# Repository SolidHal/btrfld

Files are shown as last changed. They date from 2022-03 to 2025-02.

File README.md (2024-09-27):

# btrfld and btrfld_ulp

Pronounced "butter-fold"

A foldable, portable sibling of the btrfly keyboard https://github.com/SolidHal/btrfly-keyboard

and a variant, the btrfld ulp (ultra low profile)

More images available in "FinishedPictures" folder
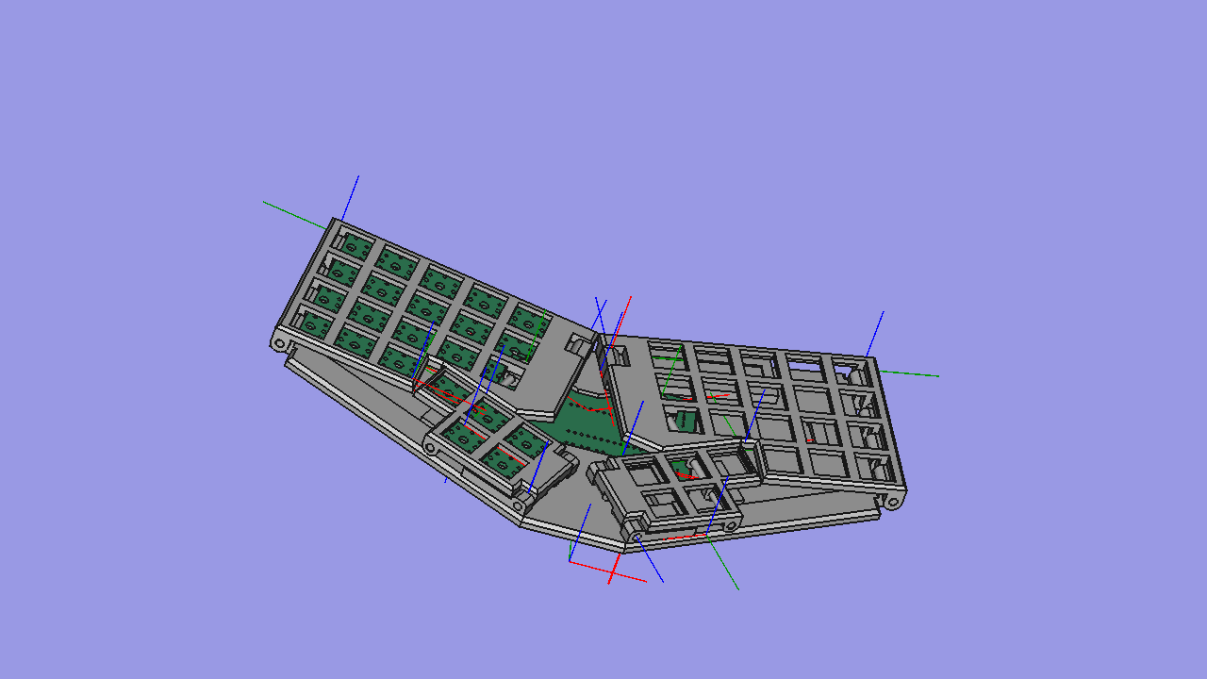
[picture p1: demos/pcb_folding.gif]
render_gif

the btrfld folding and unfolding

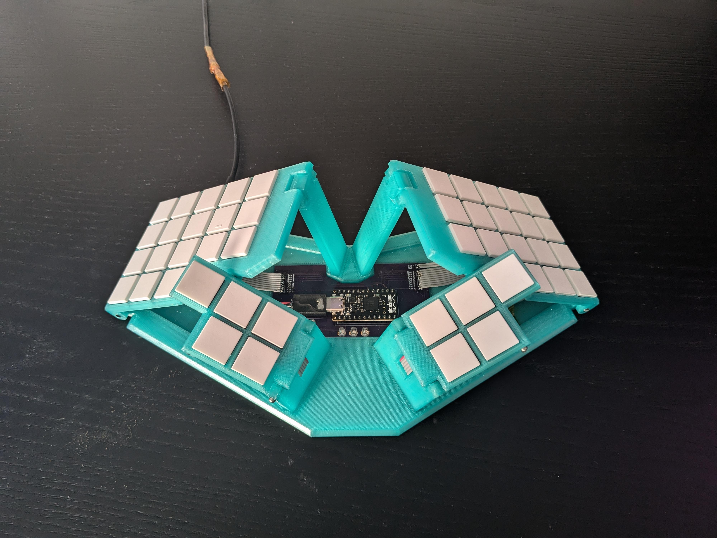
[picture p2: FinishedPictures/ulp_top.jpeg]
ulp_above

the btrfld ultra low profile (ulp) from above

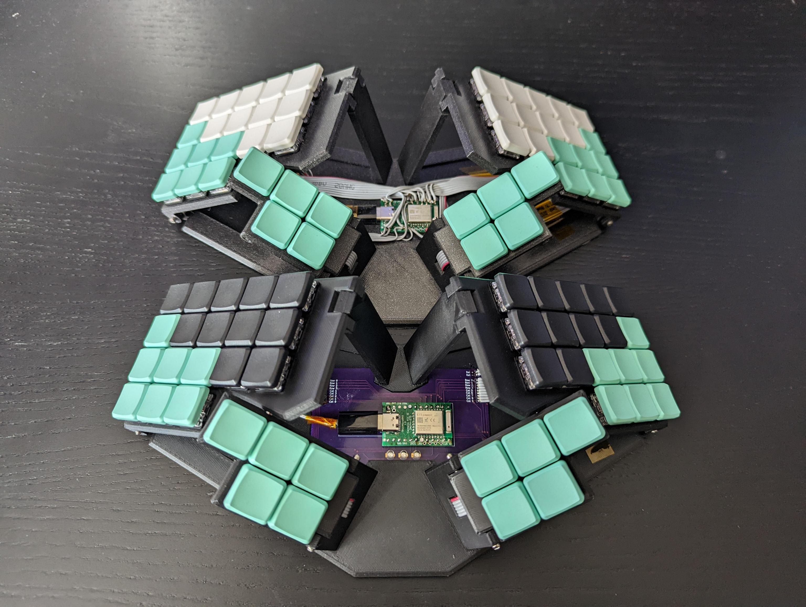
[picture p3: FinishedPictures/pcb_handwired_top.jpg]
assembled

the handwired and pcb version of the choc btrfld

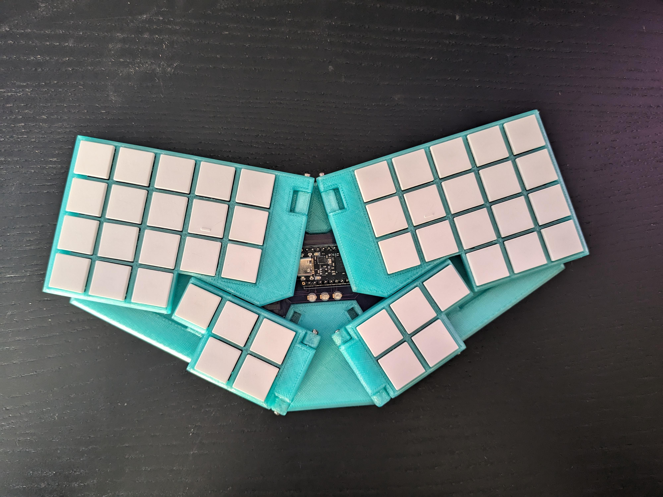
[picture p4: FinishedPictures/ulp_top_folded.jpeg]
ulp_folded

the btrfld ultra low profile (ulp) from above, folded

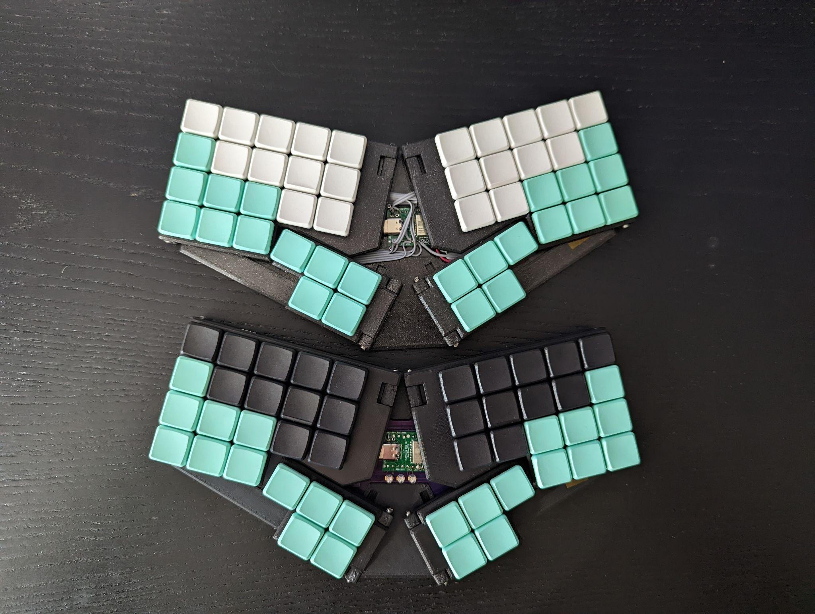
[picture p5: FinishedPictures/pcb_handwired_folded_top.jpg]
folded

the handwired and pcb version of the choc btrfld, folded up

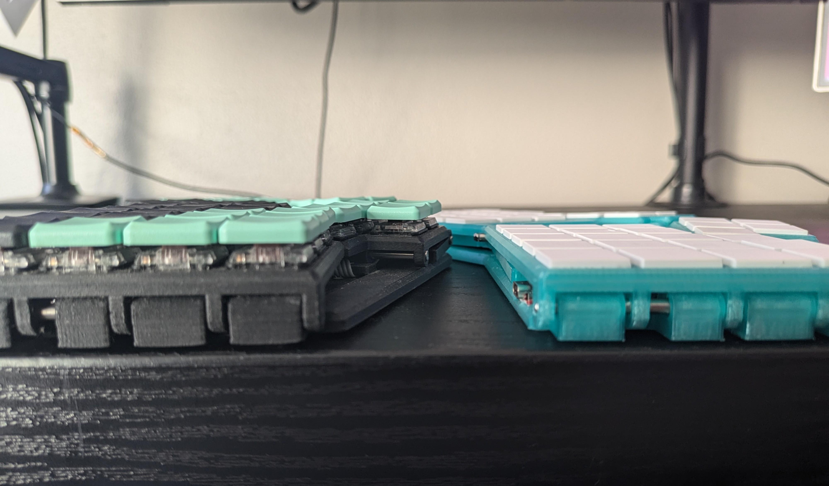
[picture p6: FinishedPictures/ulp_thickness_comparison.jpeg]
thickness_comparison

the btrfld ultra low profile (ulp) next to the btrfld pcb aka choc (its 7mm thinner!)

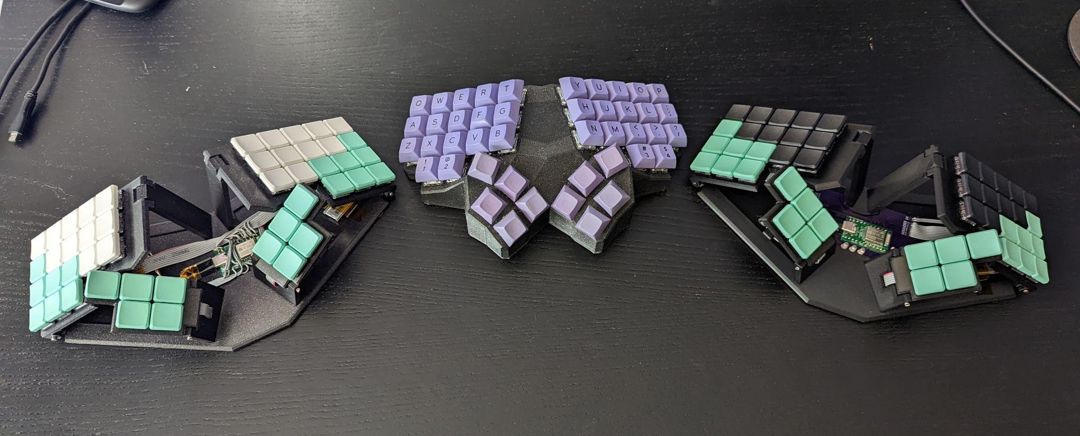
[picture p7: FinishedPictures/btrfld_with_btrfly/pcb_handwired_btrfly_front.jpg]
siblings

the handwired and pcb version of the choc btrfld with its sibling, the btrfly

## Features
- 5 key dactyl-manuform-mini thumb cluster
- flat, tented qwerty keys
- 6 extra mappable keys
- bluetooth (optional)
- folds flat for portability

- btrfld
  - choc switches
  - ~22.5 mm thick
  
- btrfld ulp
  - cherry mx ulp switches
  - ~15.5 mm thick

- 15.5mm thick (btrfld ulp)
- 22.5mm thick (btrfld)

## PCBs

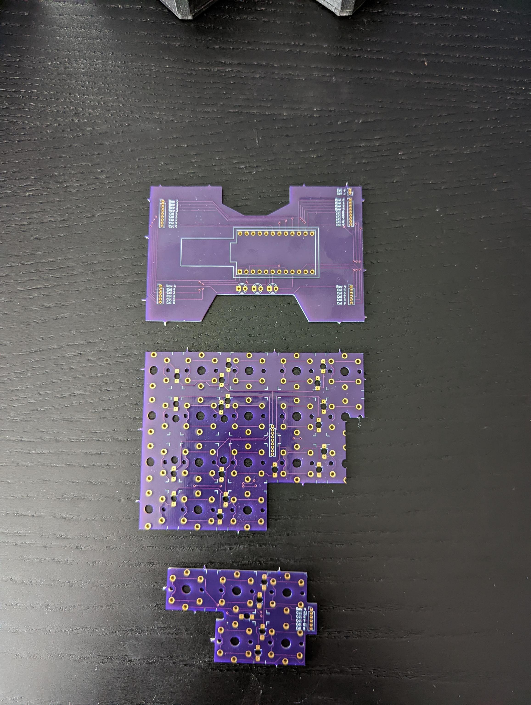
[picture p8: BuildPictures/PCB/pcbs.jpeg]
pcbs


- located in `btrfld_pcb`
- the hand and thumb pcbs are mirrored so they can be used for either hand
- 2 x btrfld_pcb
- 1 x btrfld_pcb_center
- 2 x btrfld_pcb_thumb

## Parts:

- PCBs

- USB C breakout basic breakout board
  - Used this one https://www.amazon.com/Type-C-Breakout-Serial-Connector-Converter/dp/B09KC1SMGD/
  - wiring the usb:
  ```
  For most usages, you can just connect VBUS to your 5V input, GND to ground, and D+ and D- as you expect. You can monitor the CC and SBU pins to determine cable polarity, or send side-band data. Or leave them disconnected
  ```

- A USB 2.0 USB C cable to cut up
  - USB C to Micro usb can be gotten pretty cheap

- 46 choc v1 keyswitches, keycaps OR 46 Cherry MX ULP switches
  - https://github.com/pashutk/Cherry_MX_ULP has information on finding ulp switches
  - if you choose to use ULP switches, you will need to order the solder paste stencils as well as the pcbs and get a hotplate so you can solder them
  - There aren't amazing sources of ULP key caps at this point. The best option i found was to print some. The stls can be found in `ulp_keycap` and `ulp_keycap_homenub` directories. You need a reasonably high resolution SLA printer to get functional keycaps, FDM won't work. 

- 1N4148W SOD-323F diodes
  - Tips for soldering these can be found in the assembly notes section below

- 3mm diameter steel rod
  - 2x 70.5mm
  - 2x 64.7mm
  - 2x 22.7 mm
  - 4x 14.2

- 1.27mm flat ribbon cable
  - 2 x 9 wire cables: 13 cm
  - 2 x 6 wire cables: 9.6 cm

- 1x nicenano OR bluemicro840
  - if you don't want bluetooth, you can just use a promicro instead

- 3d printed pieces, located in the STLs folder
  - 1 copy of everything besides test_fit-UnderbodyWireGuides.stl, which we need 4 of

## Print Settings:
```
Supports on buildplate
Detect Bridging
100% infill
0.20mm
PLA/PETG
```

## Assembly Tips
this process is much less tedious than hand wiring. But its still annoying in places since we are trying to keep things thin.

- btrfld (non-ulp)
    - solder the parallel wires to the hands/thumb clusters *before* placing the boards in the frame and soldering switches
    - trim the stabs on the hinge side keys of the left/right hand bodies (switches for Q,A,Z, P, ;, / keys)

- btrfld ulp
    - use your hotplate to solder the switches first, then the diodes, then the parallel wires. you can then install the pcbs into the 3d printed frames
    - you might need to use something to support balance some switches while solder, since some are only partially supported by the PCB
    - the tolerance between the keycaps and the frames is quite tight. do some testing (and likely sanding) before fully assembling to ensure nothing sticks
    
- stripping ribbon cable:
  - take an xacto knife ~3mm from the end of the cable and cut a slit until you see wire, then use your fingernail to peel the cut off section away from the rest of the cable
- use cut off diode/resistor legs to connect the controller to the center pcb
- the pcbs are designed to hold the diodes "upside down" to keep things as thin as possible. Soldering these is a little hard since they like to stick to the soldering iron.
  - get some fine point electronics tweezers
  - put a very very small amount of solder on one of the diode pads
  - place the diode, the "legs" should keep the diode from completely falling into the hole
  - hold the diode down with the tweezers, and use your iron to reflow the solder. This should hold the diode down enough for you to solder the other diode leg.
  - finally, add some more solder to the first pad
- The UnderbodyWireGuides get super glued into the holes of the pcb. See pictures of the hand underside for details.
- Once you have tested the board, use some superglue to reinforce the ribbon cable solder joints

- Reference the images in the "BuildPictures/PCB" folder

## Flash ZMK Firmware

Prebuilt firmware available in the `Firmware` directory
Bridge ground + reset twice quickly to put the bluemicro840 into flashing mode
Or press the "bootloader" key on the keyboard if you have already flashed the firmware before
then copy the firmware onto the keyboard
```
cp build/zephyr/zmk.uf2 /media/<user>/NRF52BOOT/CURRENT.UF2
```

## Build ZMK Firmware

### Github Actions Build

_This is broken until https://github.com/zmkfirmware/zmk/pull/1499 merges, do a local build instead_
fork this repo, modify the files to your hearts content
the github actions workflow will then build it for you
https://github.com/SolidHal/zmk-config-btrfld

### Local build

Grab my fork of the zmk firmware
```
git clone https://github.com/SolidHal/zmk.git
```

follow https://zmk.dev/docs/development/setup
then
```
cd zmk
cd app
west build -b bluemicro840_v1 -- -DSHIELD=btrfld
```

make pristine
```
west build -p -b bluemicro840_v1 -- -DSHIELD=btrfld
```

## Future development
- Attach trackpoint/ball or touchpad somewhere?
- latch to keep folded?
- latches to retain body/thumb extensions in base?

## Modifying
Edit `test_fit.FCStd` using FreeCad, I used version `0.19-24366`
I am by no means a FreeCad expert, so I'm sure it is built suboptimally.
The pcbs were created in kicad

## Hand Wiring Assembly Tips

### Don't hand wire this thing unless you have lots and lots of time to waste. Use the PCBs instead.

- Wiring the underside of the right/left body halves is very tedious
  - Make sure everything stays as flat as possible

- Reference the images in "BuildPictures" and "FinishedPictures" for hints on how to layout the wires

- Reference WiringGuide.png to see see the row/colomn layout

- Must trim a very very slight amount off of the center pin on keyswitches over the body/thumbcluster rod
  - switch above this must be rotated to give clearance for the rod locker

- Body/ThumbCluster Pivot Rob
  - BodyThumbRod Cap gets glued on body end of rod
  - thumb cluster end of rod gets glued in place

- Area around the body/baseplate hinge needs clearence, so keep all wires to the other side of the keyswitch

- Reference the images in the "BuildPictures" folder

### Hand Wiring Wire lengths:

#### Body -> Baseplate
9 wires
420mm

#### Thumb -> Baseplate
6 wires
240mm
70mm threaded through on the thumb side

## References

Animation:
BaseBodyAngle goes from 0 -> 32

firmware:
https://zmk.dev/docs/development/new-shield
https://zmk.dev/docs/development/setup/
https://zmk.dev/docs/troubleshooting
https://github.com/SolidHal/zmk

Friction fit redesign notes:
https://markforged.com/resources/blog/joinery-onyx
https://www.hubs.com/knowledge-base/how-design-snap-fit-joints-3d-printing/

Cherry MX ULP references:
https://github.com/pashutk/Cherry_MX_ULP

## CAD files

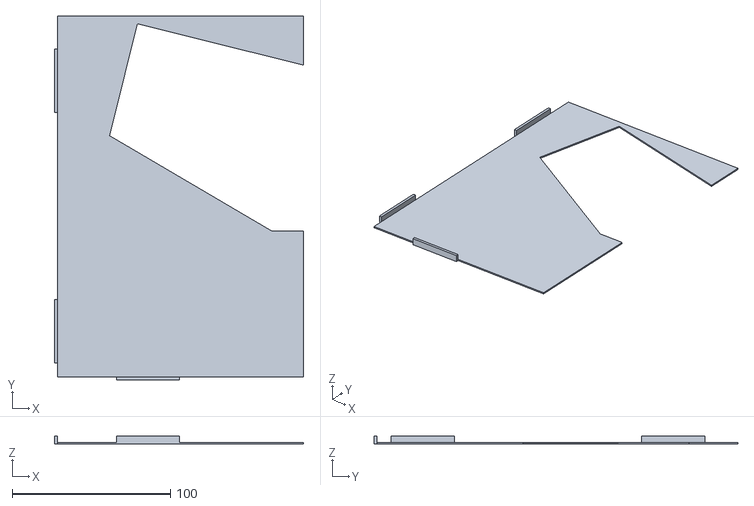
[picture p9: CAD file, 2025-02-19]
btrfld_cad_ulp/btrfld_baseplate_guide-BASEPLATE_GUIDE_RIGHT.stl
157.4 x 230.0 x 5.00

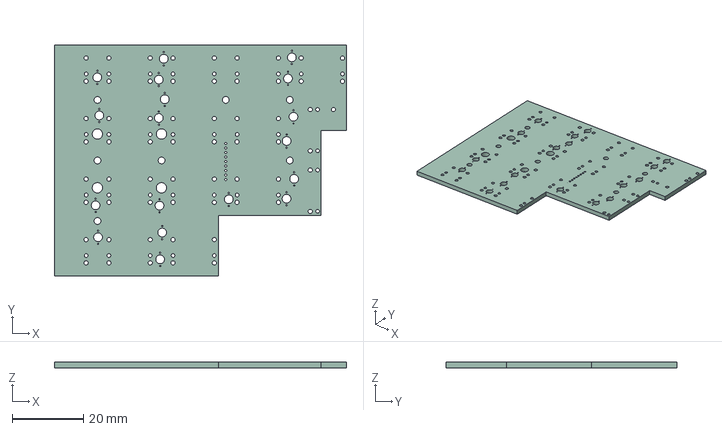
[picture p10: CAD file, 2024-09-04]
btrfld_pcb_ulp/btrfld_pcb.step
82.0 x 64.8 x 1.60 mm

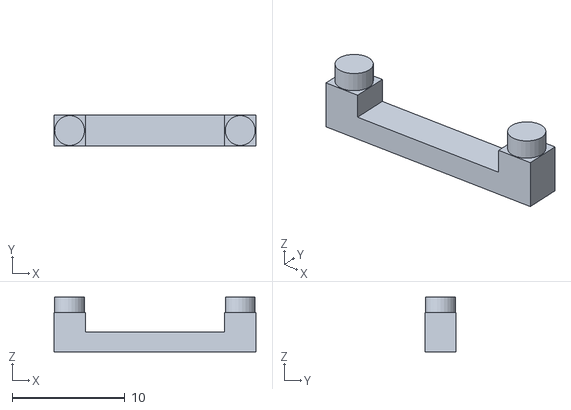
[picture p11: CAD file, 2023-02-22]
STLs/btrfld_pcb/test_fit-UnderbodyWireGuides.stl
17.9 x 2.77 x 4.87

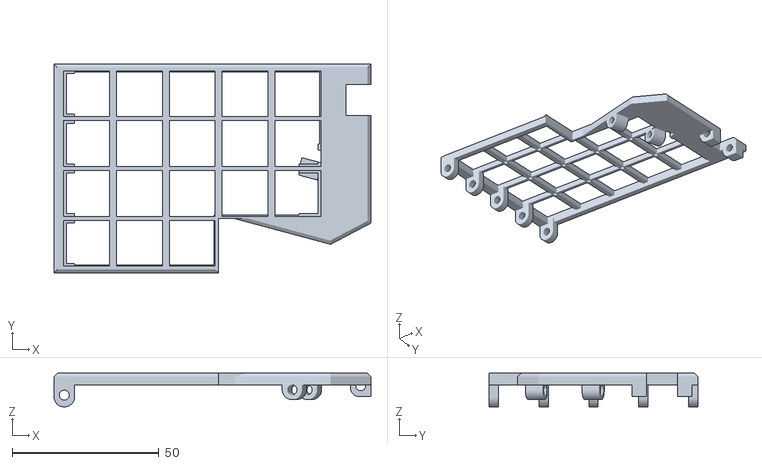
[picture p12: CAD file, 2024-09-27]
STLs/btrfld_ulp/btrfld_ulp-BodyLeft.stl
108.0 x 71.2 x 11.5

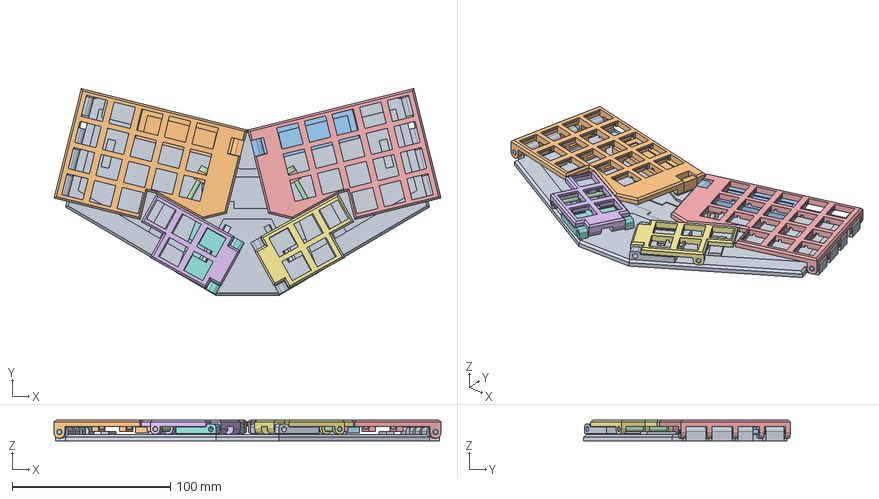
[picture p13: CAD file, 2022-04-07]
test_fit.FCStd
244.4 x 130.6 x 13.2 mm
Baseplate
BaseplateBodyRod x 2
BodyThumbRod001 x 2
Body_mirrored
ThumbLeft
ThumbLeft_mirrored002
ThumbExtensionLeft
ThumbExtensionLeft_mirrored
BodyBaseplateSupportLeft
BodyBaseplateSupportLeft_mirrored
BodyThumRodCap x 2

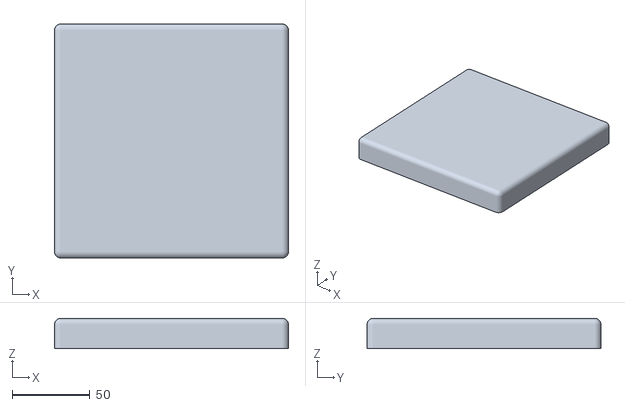
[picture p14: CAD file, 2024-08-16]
ulp_keycap/ulp_keycap.stl
150.0 x 150.0 x 19.4

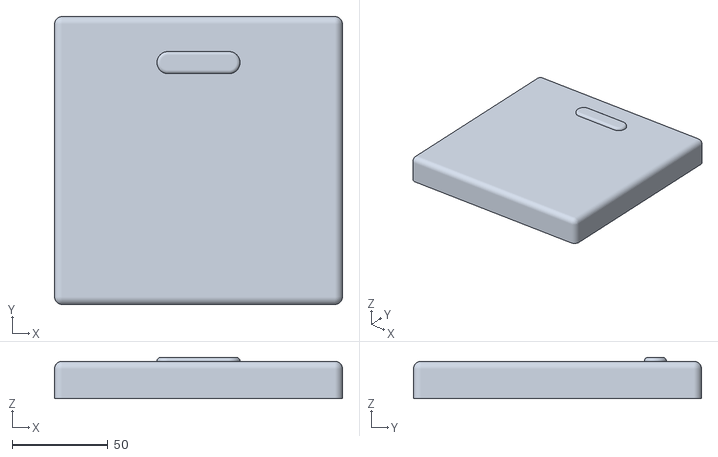
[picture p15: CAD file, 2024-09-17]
ulp_keycap_homenub/ulp_keycap_homenub-Body.stl
150.0 x 150.0 x 21.4

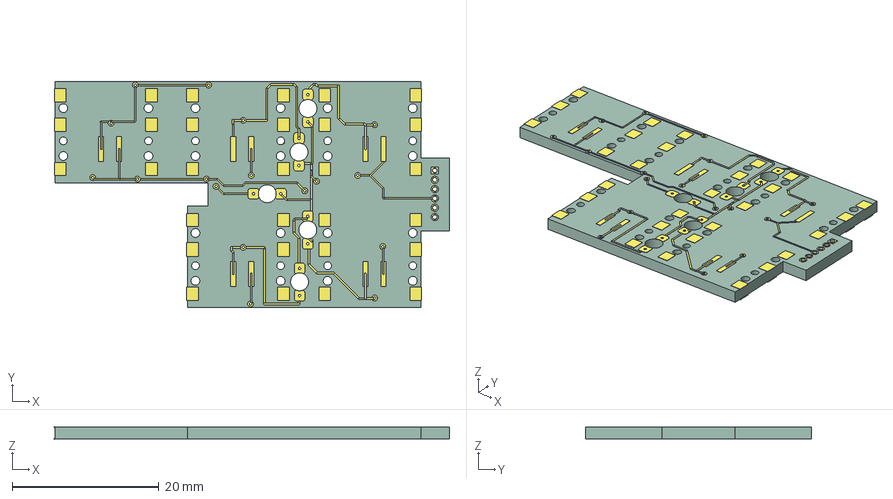
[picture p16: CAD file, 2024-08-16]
btrfld_pcb_ulp/btrfld_pcb_thumb.step
53.8 x 30.8 x 1.67 mm
btrfld_pcb_thumb_track_1
btrfld_pcb_thumb_track_2
btrfld_pcb_thumb_track_3
btrfld_pcb_thumb_track_4
btrfld_pcb_thumb_track_5
btrfld_pcb_thumb_track_6
btrfld_pcb_thumb_track_7
btrfld_pcb_thumb_track_8
btrfld_pcb_thumb_track_9
btrfld_pcb_thumb_track_10
btrfld_pcb_thumb_track_11
btrfld_pcb_thumb_track_12
btrfld_pcb_thumb_track_13
btrfld_pcb_thumb_track_14
btrfld_pcb_thumb_track_15
btrfld_pcb_thumb_track_16
btrfld_pcb_thumb_track_17
btrfld_pcb_thumb_track_18
btrfld_pcb_thumb_track_19
btrfld_pcb_thumb_track_20
btrfld_pcb_thumb_track_21
btrfld_pcb_thumb_track_22
btrfld_pcb_thumb_track_23
btrfld_pcb_thumb_track_24
btrfld_pcb_thumb_track_25
btrfld_pcb_thumb_track_26
btrfld_pcb_thumb_track_27
btrfld_pcb_thumb_track_28
btrfld_pcb_thumb_track_29
btrfld_pcb_thumb_track_30
btrfld_pcb_thumb_track_31
btrfld_pcb_thumb_track_32
btrfld_pcb_thumb_track_33
btrfld_pcb_thumb_track_34
btrfld_pcb_thumb_track_35
btrfld_pcb_thumb_track_36
btrfld_pcb_thumb_track_37
btrfld_pcb_thumb_track_38
btrfld_pcb_thumb_track_39
btrfld_pcb_thumb_track_40
btrfld_pcb_thumb_track_41
btrfld_pcb_thumb_track_42
btrfld_pcb_thumb_track_43
btrfld_pcb_thumb_track_44
btrfld_pcb_thumb_track_45
btrfld_pcb_thumb_track_46
btrfld_pcb_thumb_track_47
btrfld_pcb_thumb_track_48
btrfld_pcb_thumb_track_49
btrfld_pcb_thumb_track_50
btrfld_pcb_thumb_track_51
btrfld_pcb_thumb_track_52
btrfld_pcb_thumb_track_53
btrfld_pcb_thumb_track_54
btrfld_pcb_thumb_track_55
btrfld_pcb_thumb_track_56
btrfld_pcb_thumb_track_57
btrfld_pcb_thumb_track_58
btrfld_pcb_thumb_track_59
btrfld_pcb_thumb_track_60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

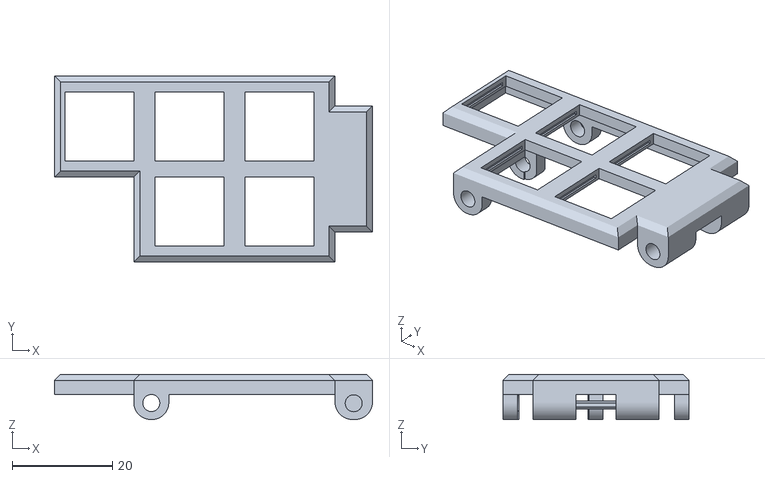
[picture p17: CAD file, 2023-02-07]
STLs/btrfld_pcb/test_fit-ThumbLeft.stl
63.5 x 37.2 x 9.00

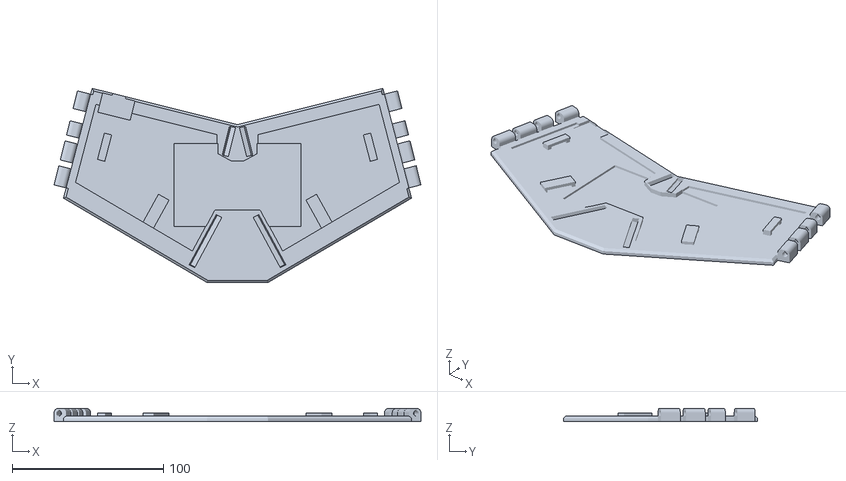
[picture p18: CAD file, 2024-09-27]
STLs/btrfld_ulp/btrfld_ulp-Baseplate.stl
242.4 x 128.3 x 8.66

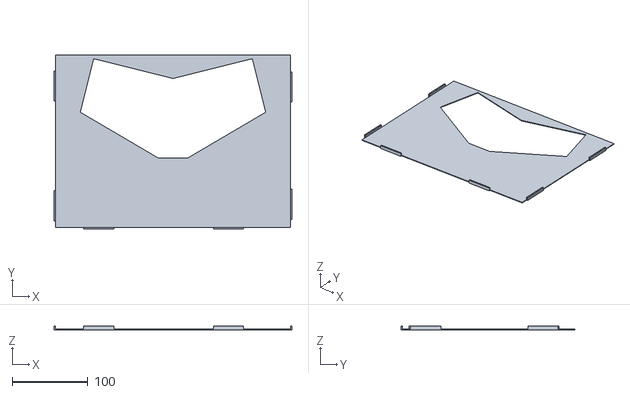
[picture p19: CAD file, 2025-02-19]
btrfld_cad_ulp/btrfld_baseplate_guide-BASEPLATE_GUIDE.stl
314.7 x 230.0 x 5.00

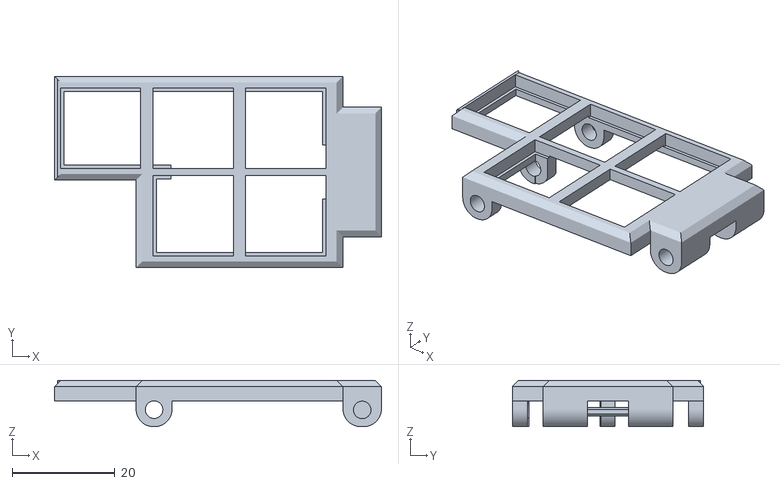
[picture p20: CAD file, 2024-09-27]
STLs/btrfld_ulp/btrfld_ulp-ThumbLeft.stl
63.5 x 37.2 x 9.00

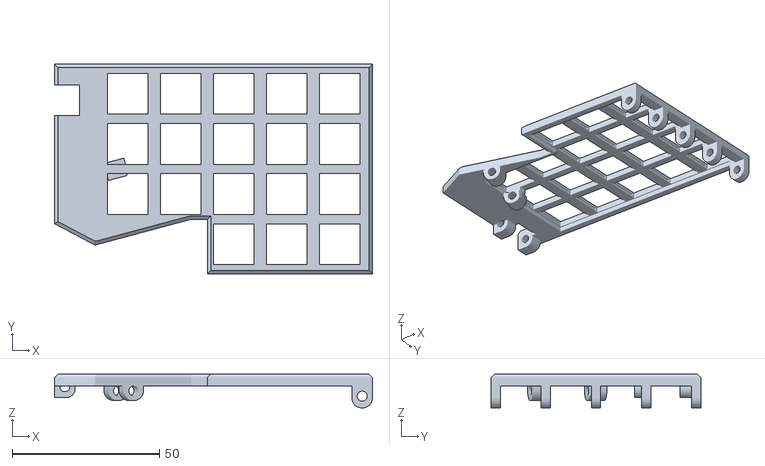
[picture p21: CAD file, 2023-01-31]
STLs/btrfld_pcb/test_fit-BodyRight.stl
108.0 x 71.2 x 11.5

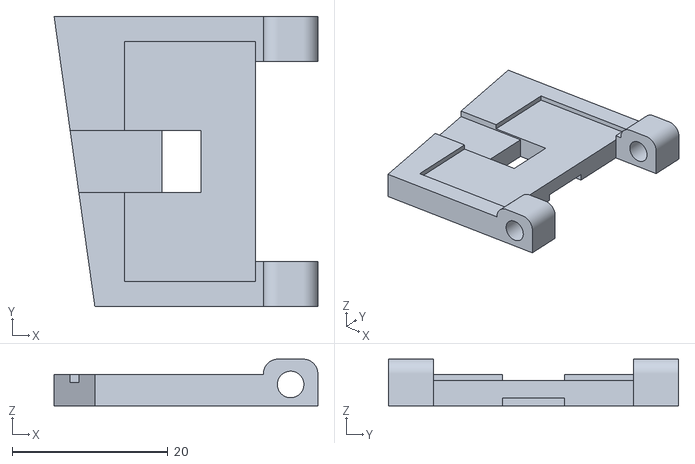
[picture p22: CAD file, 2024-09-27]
STLs/btrfld_ulp/btrfld_ulp-ThumbExtensionLeft.stl
33.8 x 37.2 x 6.00

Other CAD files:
btrfld_cad_ulp/btrfld_baseplate_guide-BASEPLATE_GUIDE_LEFT.stl
ulp_keycap_homenub/ulp_keycap_homenub.FCStd
STLs/btrfld_pcb/test_fit-ThumbRight.stl
STLs/btrfld_pcb/test_fit-Body.stl
STLs/btrfld_pcb/test_fit-Baseplate.stl
STLs/btrfld_pcb/test_fit-BodyBaseplateSupportLeft.stl
STLs/btrfld_pcb/test_fit-BodyBaseplateSupportRight.stl
STLs/btrfld_pcb/test_fit-BodyThumRodCap.stl
STLs/btrfld_pcb/test_fit-ThumbExtensionLeft.stl
STLs/btrfld_pcb/test_fit-ThumbExtensionRight.stl
STLs/btrfld_ulp/btrfld_ulp-BodyBaseSupportLeft.stl
STLs/btrfld_ulp/btrfld_ulp-BodyBaseSupportRight.stl
STLs/btrfld_ulp/btrfld_ulp-BodyRight.stl
STLs/btrfld_ulp/btrfld_ulp-ThumbExtensionRight.stl
STLs/btrfld_ulp/btrfld_ulp-ThumbRight.stl

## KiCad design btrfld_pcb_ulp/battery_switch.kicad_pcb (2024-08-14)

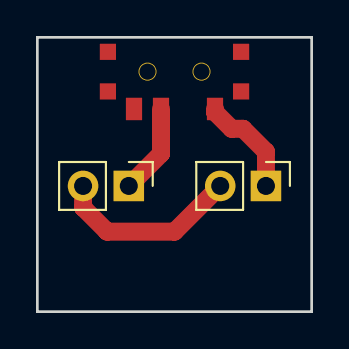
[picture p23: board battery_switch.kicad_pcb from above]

Board: 2 copper layers, 15.2 x 15.2 mm, 3 parts (0 on the bottom side), 3 nets.

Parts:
J1, J2: Conn_01x02; Pin_Header_Straight_1x02_Pitch2.54mm
SW1: SW_SPDT; SPDT_C128955

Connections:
unnamed: J1.1, SW1.2
unnamed: J1.2, J2.2
unnamed: J2.1, SW1.1

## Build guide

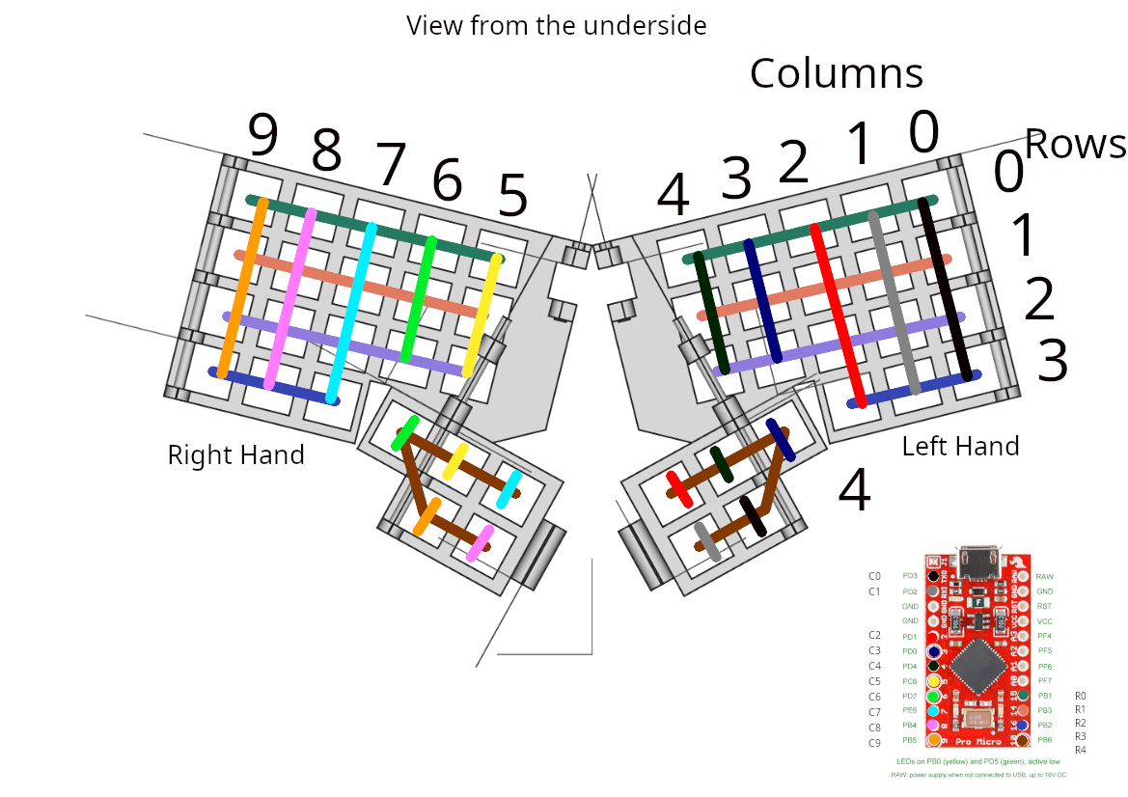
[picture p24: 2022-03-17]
WiringGuide.png

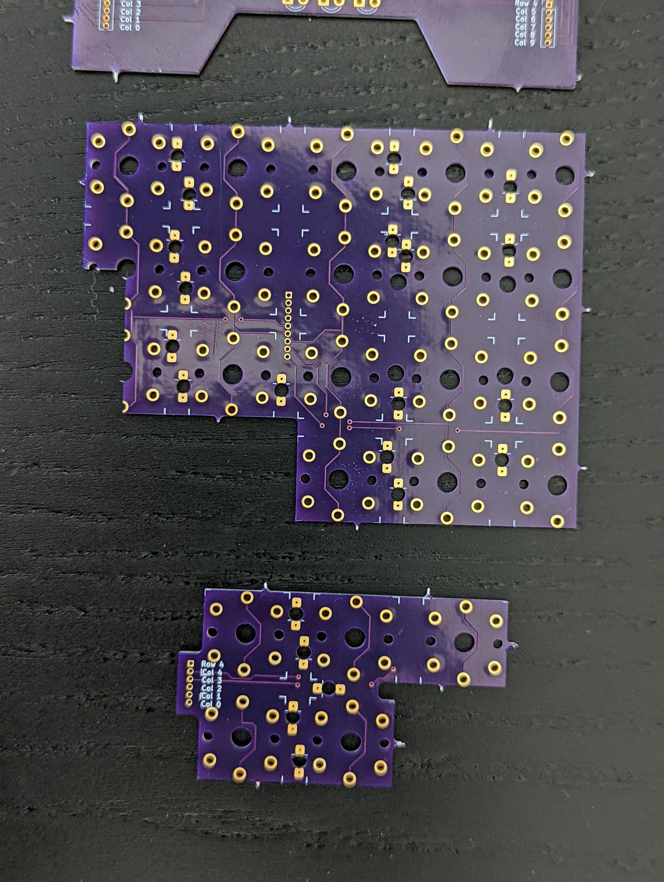
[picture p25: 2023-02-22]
BuildPictures/PCB/pcbs2.jpeg

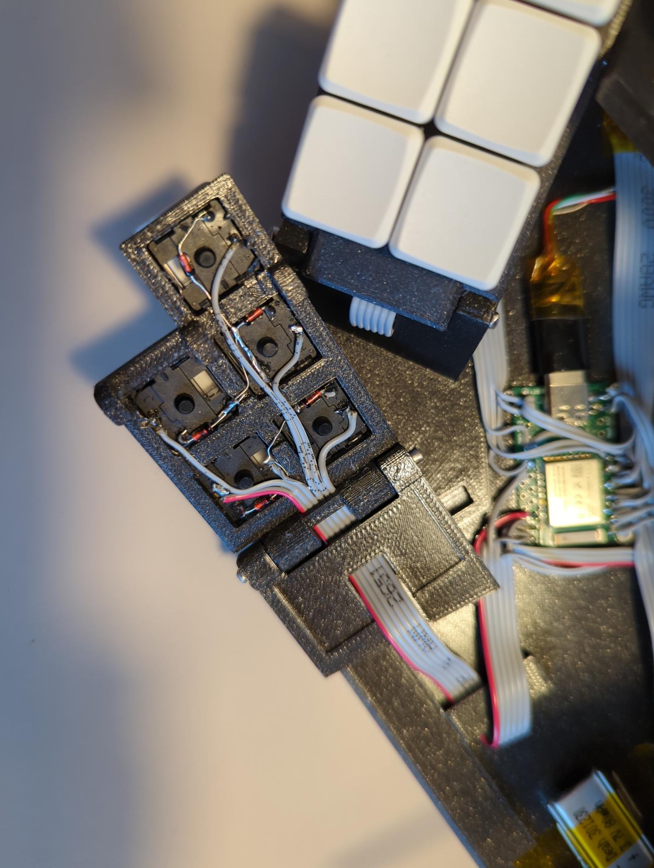
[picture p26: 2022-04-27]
BuildPictures/HANDWIRED/AllWired/RightThumbWired.jpeg

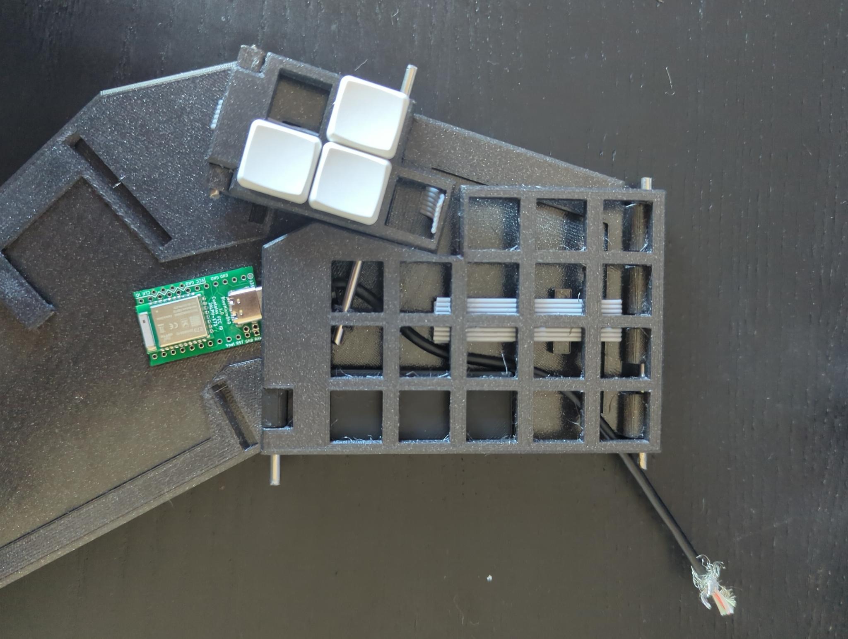
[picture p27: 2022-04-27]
BuildPictures/HANDWIRED/Assembly/routing_usb_cable.jpeg

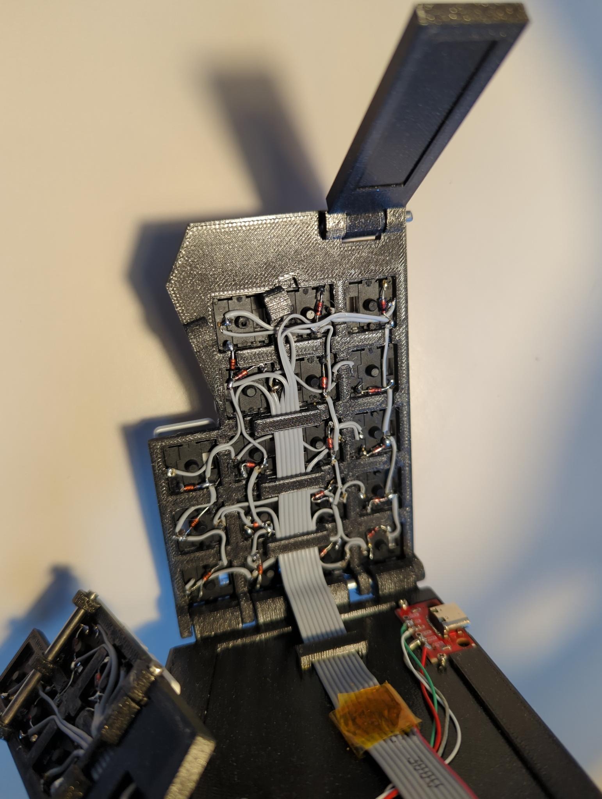
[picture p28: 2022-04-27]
BuildPictures/HANDWIRED/AllWired/LeftHandWiredUnderside.jpeg

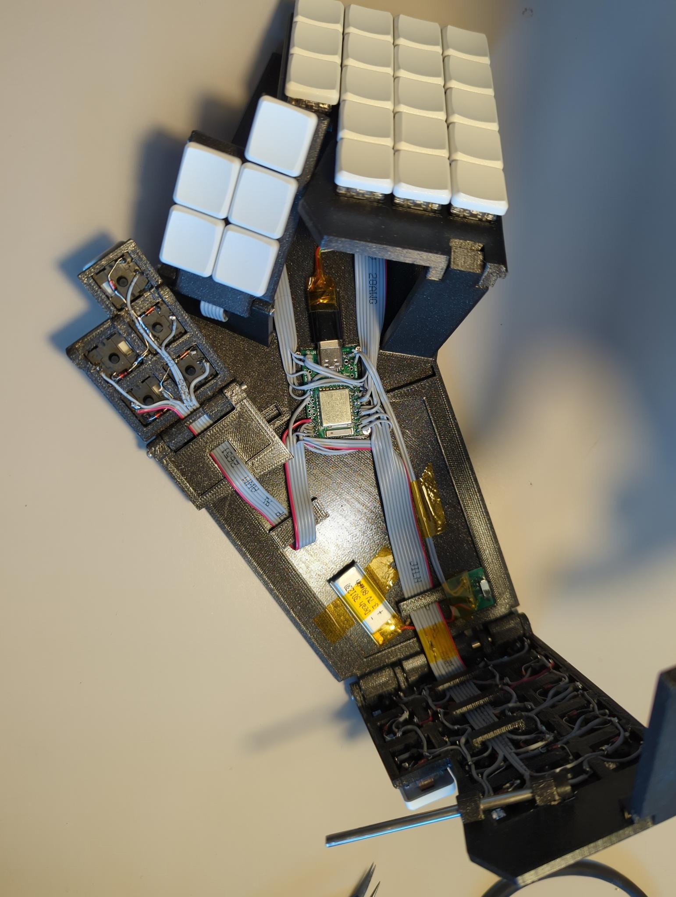
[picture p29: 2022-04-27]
BuildPictures/HANDWIRED/AllWired/RightSide.jpeg

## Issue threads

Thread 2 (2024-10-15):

loose steel rod

tangbonze, 2024-10-15:
Hello, I am trying to make this keyboard.

May I ask when I put the stainless steel rod in, it is a little loose and will fall out. Is there any way to fix it? Thank you.

machetie, 2024-11-06:
> Hello, I am trying to make this keyboard.
>
> May I ask when I put the stainless steel rod in, it is a little loose and will fall out. Is there any way to fix it? Thank you.

i dont think youll be able to fix it, youll need a thicker rod, maybe 4mm is your jam. btw what printer and material did you use?

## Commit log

2021-12-21 initial test fit files
    [test_fit.FCStd]
2021-12-21 add thumb portion to fit test
    [test_fit.FCStd]
2021-12-24 change thumb cluster angle to 40 deg
    [test_fit.FCStd]
2021-12-24 add stl, sliced files
    [test_fit-main.stl, test_fit-pin.stl, test_fit-thumb.stl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]
2021-12-27 bodies with pivot points
    [test_fit.FCStd]
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2021-12-31 adjusted pivots to fix 3mm rods
    [test_fit-main.stl, test_fit-thumb.stl, test_fit.FCStd]
2021-12-31 correct baseplace length
    [test_fit.FCStd]
2022-01-01 adjust hole size, baseplate size from 2nd draft print
    [test_fit.FCStd]
2022-01-01 fix demo video, seems freecad outputs weirdness
    [test_fit.FCStd]
2022-01-01 need to figure out thumb baseplate attachement
    [test_fit.FCStd]
2022-01-01 try smaller support for thumbs
    [test_fit.FCStd]
2022-01-01 make thumb right its own piece
    it needs to be unique from thumb left
    [test_fit.FCStd]
2022-01-04 cleanup thumb sketch
    - begin work on thumb extension
    [test_fit.FCStd]
2022-01-04 rough shape of thumb extension figured out
    [test_fit.FCStd]
2022-01-04 get better idea of the thumb extension
    [test_fit.FCStd, thumb_extension_bak.FCStd]
2022-01-04 magnetic connector checkpoint
    making the extension wide enough to fit the magnetic connector
    requires either
    1) putting a hole in the baseplate
    2) making the space between the baseplate and the bode/thumb larger
    (2) is bad because we don't want to increase the thickness of the entire
    keyboard
    (1) requires a hole right where the baseplates magnetic connector would
    go, which will not work.
    [test_fit.FCStd]
2022-01-05 mapped out one side of extension slot
    [test_fit.FCStd]
2022-01-05 bottom, top sketch of baseplate hole for thumb extension
    [test_fit.FCStd]
2022-01-06 setup right extension
    cleanup repo
    [test_fit-main.stl, test_fit-pin.stl, test_fit-thumb.stl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]
2022-01-06 baseplate thumb extension holes slightly larger
    added route for baseplate body support hinge
    [test_fit.FCStd]
2022-01-07 increase thumb extension gap
    [test_fit.FCStd]
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2022-01-07 reduce clearance on thumb extension pivot
    [test_fit.FCStd]
2022-01-07 create sketchs for top and bottom of extension slot
    [test_fit.FCStd]
2022-01-07 finally got the subtractive loft to work
    [test_fit.FCStd]
2022-01-08 after a bunch of trig, top of slight is aligned
    [test_fit.FCStd]
2022-01-08 make body/baseplate hinge 1.7r
    [test_fit.FCStd]
2022-01-08 make long holes teardrop shaped
    [test_fit.FCStd]
2022-01-09 make baseplate body support hinge larger
    [test_fit.FCStd]
2022-01-09 correct baseplate body angle
    [test_fit.FCStd]
2022-01-09 add print time reducer for body
    [test_fit.FCStd]
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2022-01-09 add thumb extension stopper
    [test_fit.FCStd]
2022-01-09 reworking baseplate/body support, checkpoint
    [test_fit.FCStd]
2022-01-11 add symmetric body/baseplate support
    [test_fit.FCStd]
2022-01-11 completed baseplate body support
    [test_fit.FCStd]
2022-01-11 correct body support spacing
    [test_fit.FCStd]
2022-01-11 move supports in a bit to make slicer happy
    [test_fit.FCStd]
2022-01-12 remove external references on body pieces
    [test_fit.FCStd]
2022-01-12 move thumb clusters inward
    [test_fit.FCStd]
2022-01-12 adjust thumb cluster angle
    [test_fit.FCStd]
2022-01-13 clean up attactment points
    [test_fit.FCStd]
2022-01-13 move thumb cluter hinge up
    [test_fit.FCStd]
2022-01-13 Revert "move thumb cluter hinge up"
    This reverts commit d1044715d7c4dff2feddb821aab7251de043a833.
    [test_fit.FCStd]
2022-01-13 fixup thumb extension baseplate slots
    [test_fit.FCStd]
2022-01-13 change angle of thumb cluster to body
    [test_fit.FCStd]
2022-01-13 fixup thumb extension and thumb placement to fit angle change
    [test_fit.FCStd]
2022-01-13 correct thumb cluster body linear extension
    [test_fit.FCStd]
2022-01-13 correct thumb extension baseplate slots
    [test_fit.FCStd]
2022-01-13 make the quick print cutout better
    [test_fit.FCStd]
2022-01-14 move thumb cluster closer
    [test_fit.FCStd]
2022-01-15 move thumb cluster even closer
    [test_fit.FCStd]
2022-01-15 correct thumb angle, correct extension slots
    [test_fit.FCStd]
2022-01-20 trim baseplate height, tighten thumb hinges
    [test_fit.FCStd]
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2022-02-25 add wiring guide base image
    [test_fit.FCStd]
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2022-03-26 create baseplate wiring cavity
    - picked out controller location
    - add STLs
    [test_fit-Baseplate.stl, test_fit-Body.stl, test_fit-BodyBaseplateSupportLeft.stl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]
2022-03-29 map out wire routing
    [test_fit.FCStd]
2022-03-29 add bodythumbcluster rod cap
    [test_fit.FCStd]
2022-03-29 add body/thumb rod caps to assembly
    [test_fit.FCStd]
2022-03-29 added wire routing to body, choc retaining clip slots to body
    [test_fit.FCStd]
2022-03-29 add pocket to body baseplate support for choc key pins
    [test_fit.FCStd]
2022-03-29 revert thumb extension shrink
    [test_fit.FCStd]
2022-03-29 added thumb extension wire guide, adjusted baseplate cavity
    [test_fit.FCStd]
2022-03-30 adjust choc clip slots, wiring guides on thumb
    [test_fit-Baseplate.stl, test_fit-Body.stl, test_fit-BodyBaseplateSupportLeft.stl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]
2022-03-30 add thumb cluster wire management to baseplate
    [test_fit-Body.stl, test_fit-ThumbLeft.stl, test_fit.FCStd]
2022-03-30 added wire management to body
    increased wire slots from 1mm -> 2mm
    [test_fit.FCStd]
2022-03-30 added 1.2mm chamfer to body, thumb
    [test_fit.FCStd]
2022-03-30 shrink body thumb rod cap to 1.6mm
    [test_fit-Baseplate.stl, test_fit-Body.stl, test_fit-BodyBaseplateSupportLeft.stl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]
2022-03-31 adjst body cable management
    [test_fit.FCStd]
2022-03-31 add usb breakout board cutout, adjust baseplate wire management
    [test_fit.FCStd]
2022-04-01 add controller cutout to baseplate
    [test_fit.FCStd]
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2022-04-01 increase body wire manager slot side
    [test_fit.FCStd]
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2022-04-27 Add images, demo gif
    [test_fit-Baseplate.stl, test_fit-Body.stl, test_fit-BodyBaseplateSupportLeft.stl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]
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2023-01-27 correct column 5 trace on center pcb
    add center pcb to cad
    [btrfld_pcb_center.kicad_pcb]
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2023-02-07 fixup spacing around thumb cluster pcb
    [test_fit-ThumbLeft.stl, test_fit-ThumbRight.stl]
2023-02-07 fixup flipped diode holes so copper connects pads on either side of board
    also fixup some tracing while we are at it
    [btrfld_pcb.kicad_pcb, btrfld_pcb_thumb.kicad_pcb]
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2024-08-14 add cherry mx ulp pcb, begin work on cad
    [battery_switch.kicad_pcb, btrfld_pcb.kicad_pcb, btrfld_pcb.kicad_sch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]
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2024-08-16 widened key holes, need to fix right hand
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2024-09-04 place and test body pcb and cad screw holes
    [btrfld_pcb.kicad_pcb, btrfld_pcb.step]
2024-09-04 added faster holes to pcb & cad thumb, reviewed traces
    [btrfld_pcb.kicad_pcb, btrfld_pcb_thumb.kicad_pcb]
2024-09-04 remove pads & holes that fall of the edge of the board
    [btrfld_pcb.kicad_pcb, btrfld_pcb_thumb.kicad_pcb]
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2024-09-17 correct keycap home nub location
    [ulp_keycap_homenub-Body.stl, ulp_keycap_homenub.FCStd]
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
